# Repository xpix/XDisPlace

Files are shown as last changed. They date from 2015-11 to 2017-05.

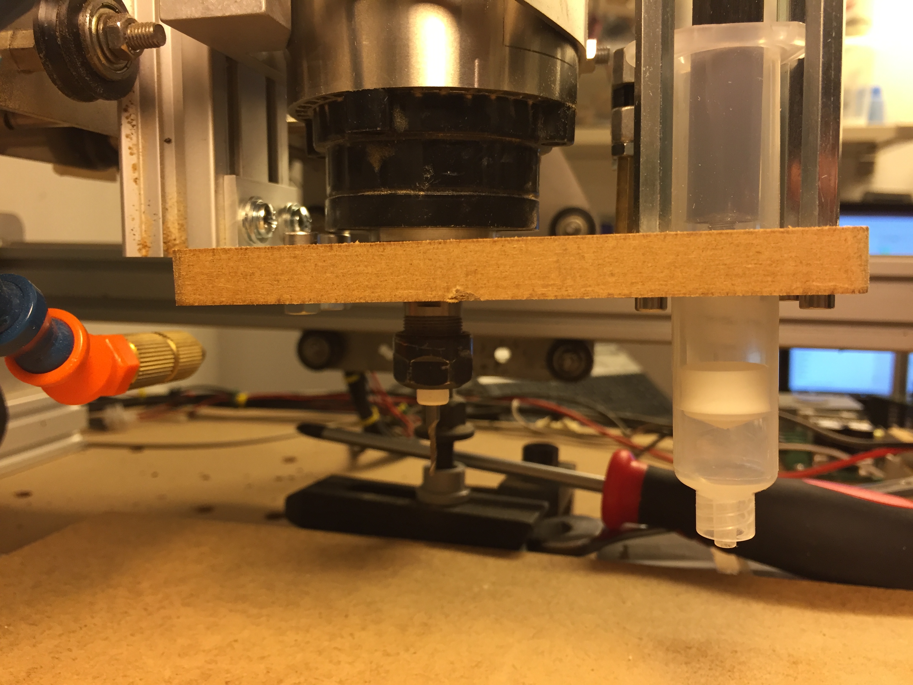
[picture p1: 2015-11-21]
Images/IMG_0289.JPG

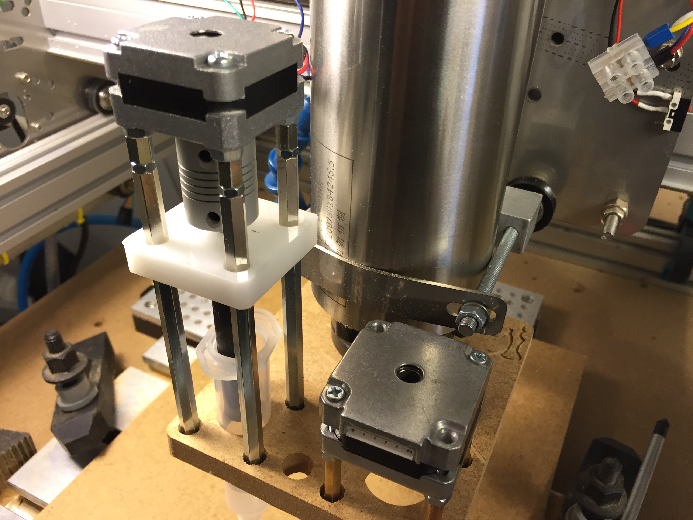
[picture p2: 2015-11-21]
Images/IMG_0288.JPG

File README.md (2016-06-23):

# XDisPlace
XDisplace are a complete solution to mill, dispense solder paste and pixk and place components to a pcb in one process!

I made a long video playlist to explain all my steps to develop this Feature. Please watch it:

Solder Dispense Feature Playlist (https://www.youtube.com/playlist?list=PLYPTUTcLMTK74VLPE4gAp8Kz8d09ipsBq)

A nice explain why XDisPlace exists from this website: http://nerdclub-uk.blogspot.de/2016/06/sacrificing-pins-to-make-pcb-layout.html

Wherever possible, we like to try to keep to single-sided boards, even for designs going "into production". While it's easy to throw together a poorly-designed, double-sided PCB and send it off to a factory to get made up, that means delays and waiting; and quite often, a much slower development cycle - particularly if, like us, you have an iterative design process!

Keeping designs to single-sides means you can knock up some ferric chloride, try out your design and have a working board in hours, not days or even weeks.

But even if your project isn't time sensitive and you can afford to wait weeks, between ordering and receiving your boards, it often means either:

a) when the board needs redesigning (because you forgot to include the ground plane, or re-route that pin you left a "to-do" note against and then ignored - don't pretend it hasn't happened) you've got another four-to-six-week wait while the new boards arrive OR

b) tack-soldering a few wires and slicing traces with a craft knife, just to get the thing up and working.

Either way, you end up with a less-than ideal PCB or weeks and months of delays.
Homebrew etching is ugly. The results are less than perfect. It's messy and you'll stain your hands yellow for days (and possibly the sink forever if you're not careful). But it gets a result - quickly.

So if you need to redesign a board, you can simply print out a new design, slap down some toner transfer, whack it in some ferric chloride and an hour or two later, you've an amended design. And once you're absolutely sure your design works, you can send the exact same PCB layout to your favourite factory/fab-house and then wait (one time only) for the nice, shiny, silk-screened-and-solder-masked versions to arrive, for the final product.

That's why we still make our own PCBs.
It might not be fashionable (in fact there are plenty people who ask why, when having PCBs manufactured is so cheap, would you want to still etch your own boards) but it is quick and allows the iterative design process to complete fully - no boards with bits of wires tacked on because we've committed to a single design now (even with faults/errors) and can't wait any longer to get the thing soldered up and tested! That's why we favour single-sided designs.

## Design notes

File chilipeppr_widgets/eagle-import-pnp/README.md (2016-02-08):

Presentation:
-------------

Philosophy:
* "simple as possible"
* no camera needed cuz accurate position of PNP Holder
* automaticly sortet components to Trays and pockets
* position on CNC in every case the same
* after homing you can use it

Platform: (Photo)
* milled in MDF, future Delron(POM) or Aluminium
* Holes for accurate position on whaste board
* Trays or Feeder numbered from 1 ... 8
* Pockets lettered from A-L
* Screw's to hold PCB in 1mm deep Pocket
* Tunnels for Probe wire's
* Calibrate block to find zero point

Strategy for Trays:
* Nozzle move the smd tape to next position
   https://youtu.be/CVlad7l9HvI?t=463
* Structure of a tray: 
   http://www.token.com.tw/chip-resistor/smd-resistor1.htm
* 1. move nozzle to zero line (cambam) of Tray
* 2. move 1.75mm in X Direction
* 3. deep nozzle in a hole 
* 4. move tape 4mm in Y direction 
* 5. go back to smd position and get it

Strategy for Pockets:
* Nozzle move the smd pocket to pocket and get smd component
   https://youtu.be/CVlad7l9HvI?t=463
* 1. move nozzle to zero line (cambam) of Tray
* 2. move 1.75mm in X Direction
* 3. deep nozzle in a hole 
* 4. move tape 4mm in Y direction 
* 5. go back to smd position and get it

PNP Plugin: 
==========
* Parameters 
   * only PNP gcode
      * send only this pnp gcode to machine
      * can use for pcb's made in china or osh park with stencil
   * packagesTrays, packagesPockets:
      * decide of this input which smd component are sorted to tray or pockets
      * user can input regular expressions (DIL\d+-SMD)
   * safetyHeight:
      * heighest point for nozzle to move without problems
      * Screw's height are ~10mm
   * RotationAxis:
      * axis on the second grbl controller to rotate the nozzle stepper for right direction
      * resistor in example
      * all roation values can see in trays/pockets table
   * Nozzle Outsidediameter
      * image: noki_nozzle.jpg 
      * diameter on the smallest side of noozle
      * use for calculate the way to next cmp in tape
   * PNP Holder
      * load pnp holder data from json file
      * designs for more holder 
      * horicontal, vertical Design

* Configure trays
   * Display table (eagle with mosfet)
   * automatic sort function to make the process very simple
   * explain Row's 
   * The components were sorted according to their value
   * same value, then same tape or pocket
   * rotation are very important for bigger components in pockets, to know for right position in pocket (check eagle package)
   * Ignored data are components they are ignored becouse thay are not exists in packagesPockets or packagesTrays

* 3D Platform model
   * Text describe the name of pocket/trays or the smd component sorted to this tray
   * the color and text let us know if the tray busy or free
   * now you can sort all components to trays/pockets

Function (physics)
* plugin load 

https://youtu.be/CVlad7l9HvI?t=297

PNP-Flow for user
------------
- calibrate
- set trays
- run PNP

A. Widget:
=========
JS
---------
* stepsCalculate() : Calculate calibrated Step settings and ask for automatic set
* calibrate() : action and run all calibration steps and save the data to localspace
* displayPlatform(model, pos) : get via JSON model and display this on 3d workspace
* getComponent( eagle component ) : get component and his position in Tray
* StrategyForGet( tray type ) : use a process in gcode to get the component from a i.e. tape
* StrategyForPut( component ) : use a process in gcode to put the component to pcb (rotate and move to correct position)
* setChannel(GPIO, on|off) : to switch GPIO on or of, check the SPJS with GPIO support
* setVacuum(on|off) : Open or close the magnetic air ventil
* onAddGcode(gcode) : add the segments to main gcode (get publish from egale-import widget)

Calculate move
--------------

- Hole in tape: 1.5mm / radius = 0.75mm
- Outsidediameter Nozzle: 1.0mm = 0.5mm
- move to corner: 0.75mm - 0.5mm = 0.25mm Y-direction
- move to next cmp: 4mm + 0.25mm = 4.25mm

HTML
---------
Checkbox to use PNP
(Calibrate Section)
* calibrateMillDiameter : calibrate mill inside diameter
* sizeCalibrateBlock : Size of calibrate Block 15.02x15.01
* Button "Calibrate"

(PNP Section)
* displayPNP : display model in 3d or not
* Button "Sort" : open a new message box with table (component / Tray)

here a try to make a flow:

1. Topic Calibrate
==================

* first be sure your Machine are calibrated. We mill a quadrat and inner circle, please measure the result with a caliper width from Box and Diameter from circle have to between 19.90 mm and 20.10 mm. (Example gcode file cambam/CalibrateExample.CalibrateBox.nc) For Z-Axis, measure the height between circle and Box, Calues between 4.95 and 5.05 are ok. 

If not between this values, then you can adjust the steps/mm for every axis. 

   I.e. You measure 19.5mm in X and Y, and your settings are 40 steps/mm. 

Formula for a probe with 
(real) 20mm diameter and 
40 steps/mm:

We need 800 steps for 20mm:
      40 steps * 20mm = 800; 

The machine measure 19.5mm:
      19,5mm / 800 = 0,024375; 

in mircon:
      20mm / 0,024375 = 820,5128205128205; 

Result are 41,026
      820,5128205128205 / 20 = 41,02564102564103; 

   Then calculate: 
      40 steps * 20mm = 800; 
      19,5mm / 800 = 0,024375; 
      20mm / 0,024375 = 820,5128205128205; 
      820,5128205128205 / 20 = 41,02564102564103;
      ==============
      use 41,025 for steps/mm

   javascript calculate:
      var orignalSteps = 40;
      var orignalDistance = 20;
      var measuredDistance = 19.5;
      var micron = (measuredDistance / (orignalSteps * orignalDistance));
      var realSteps = (orignalDistance / micron) / orignalDistance;
      
* use a used endmill with a shaft of 3.0 mm to 4mm (input box) and put this --verkehrt herum-- in collar of spindle.
* move spindle in the middle of calibrate block (camera?)
* Push Button "Calibrate" with calibrate Block in the middle of PNP Platform.
* Call Touch Plate with height 2.0mm
* Push the Button "Calibrate" and enjoy it :)

   * move to Saveheight
   * move to X-10 Y0
   * move to Z-1
   * calibrate X-Axis to touch on right side

   * move to Saveheight
   * move to X0 Y-10
   * move to Z-1
   * calibrate Y-Axis to touch on top side

   * move to Saveheight
   * move to X10 Y0
   * move to Z-1
   * calibrate X-Axis to touch on left side

   * move to Saveheight
   * move to X0 Y10
   * move to Z-1
   * calibrate Y-Axis to touch on bottom side

* calculate (X/Y)Pos -/+ (inoutdiamter/2), care over sizeCalibrateBlock
* We know the position of the calibrate block. With this information we know everything about position of trays and PCB etc.pp.
* IMPORTANT: Save the Machineposition on a localspace to help user. If you lose this position, than you can home your machine and go back to this position to find you center/zero point of PNP Platform!
* Drive the calibrate crosshairs on left/right/top with camera and check if cross in middle

Done as Calibrate Widget: 
http://chilipeppr-calibrate-xpix.c9users.io/

Topic PickAndPlace
==================

* Display PNP Platform as 3d Object in 3d world (table with data load as ajax) use threejs/editor to build a model
* load JSON Table with positions of all trays and PCB Holder
* Display a Table with all Trays and a list of components
   * getComponent( eagle component );
      - get and move to tray position
      - get strategy to get a component
      - write gcode
   * setComponent( eagle component );
      - get and move to pcb position
      - get put strategy to put a component to pcb
      - write gcode

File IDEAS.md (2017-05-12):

Here some intresting links for SolderDispenser:

## use soldermask widget from j.lauer

to generate the gcode we have to use a formula, i found this in slicr:
  https://github.com/alexrj/Slic3r/blob/master/lib/Slic3r/GCode/PressureRegulator.pm#L39-L63
````
# First calculate relative flow rate (mm of filament over mm of travel)
my $rel_flow_rate = $info->{dist_E} / $info->{dist_XY};

# Then calculate absolute flow rate (mm/sec of feedstock)
my $flow_rate = $rel_flow_rate * $F / 60;

# And finally calculate advance by using the user-configured K factor.
my $new_advance = $self->config->pressure_advance * ($flow_rate**2);
````

Think about the simplest workflow for dispenser:
*   use the flow of 3d print
*   means first make a line with calculatet 0.2mm on the side off pcb (length & witdth configurable)
*   build a webservice dispense, this will translate coordinates to dispenser gcode

````
start 10,10;end 20,10;fill:rectangle
json='"start":[10,10], 
     "end":[20,20],
     "fill":"rectangle"     '
````
Will translate to fill, use modified slicr modul for this on server.
It's able to use the Fill Modules from Slicr:
````
# honeycomp example:
    my $pattern = 'honeycomb';
    my $config = Slic3r::Config->new_from_defaults;
    $config->set('fill_pattern', $pattern);
    $config->set('external_fill_pattern', $pattern);
    $config->set('perimeters', 1);
    $config->set('skirts', 0);
    $config->set('fill_density', 20);
    $config->set('layer_height', 0.05);
    $config->set('perimeter_extruder', 1);
    $config->set('infill_extruder', 2);
    my $print = Slic3r::Test::init_print('20mm_cube', config => $config, scale => 2);
    my $gcode = Slic3r::Test::gcode($print);
````

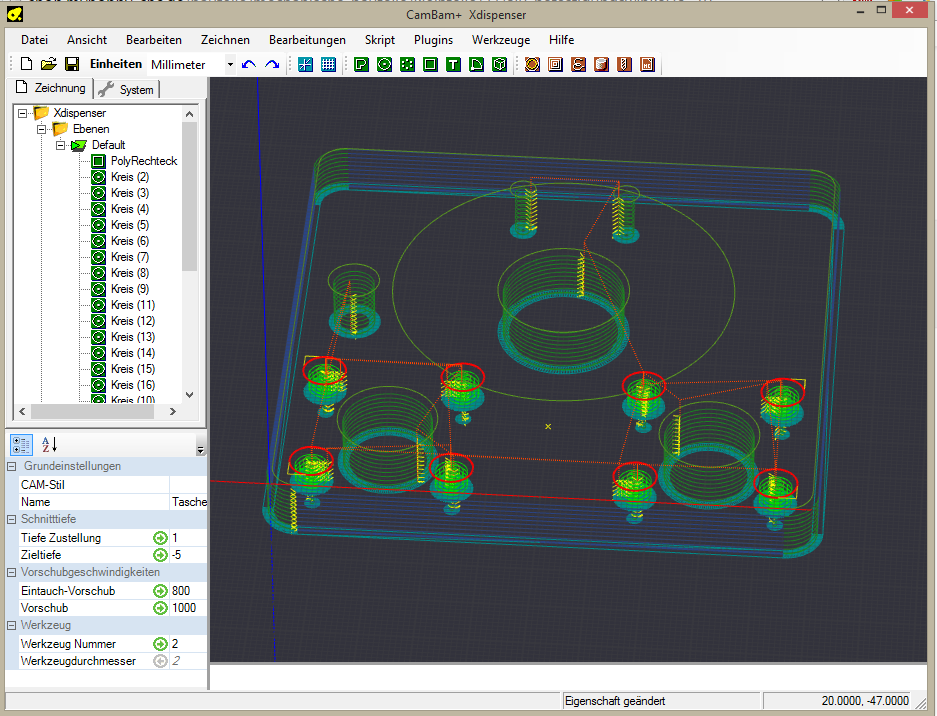
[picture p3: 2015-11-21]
Images/cambam-plus-0.9.1_s.png

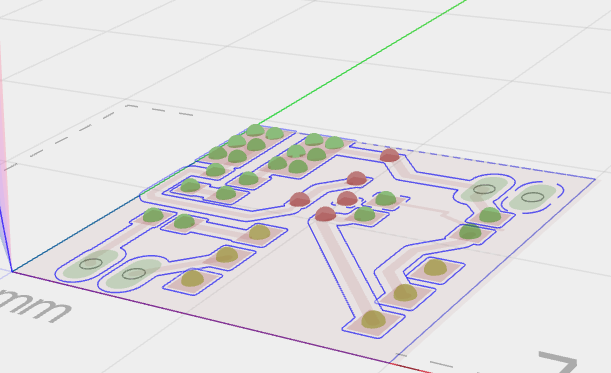
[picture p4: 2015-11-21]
Images/Drops.PNG

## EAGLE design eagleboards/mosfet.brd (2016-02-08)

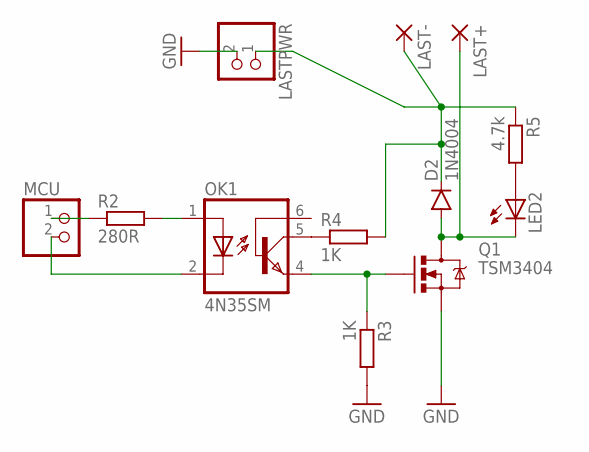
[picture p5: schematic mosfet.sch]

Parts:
D2: 1N4004; SOD-123
LAST+: WIREPADSMD2,54-5,08; SMD2,54-5,08
LAST-: WIREPADSMD2,54-5,08; SMD2,54-5,08
LASTPWR: PINHD-1X2; 1X02
LED2: LEDCHIP-LED0805; CHIP-LED0805
MCU: PINHD-1X2; 1X02
OK1: 4N35SM; DIL6-SMD
Q1: TSM3404; SOT23-3
R2: 280R; R0805
R3, R4: 1K; R0805
R5: 4.7k; R0805

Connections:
GND: LASTPWR.2, Q1.2 (S), R3.2
LAST+: D2.C, LAST-.1, LASTPWR.1, R4.2, R5.1
LAST-: D2.A, LAST+.1, LED2.C, Q1.3 (D)
unnamed: OK1.1 (A), R2.2
unnamed: MCU.1, R2.1
unnamed: MCU.2, OK1.2 (C)
unnamed: OK1.4 (EMI), Q1.1 (G), R3.1
unnamed: OK1.5 (COL), R4.1
unnamed: LED2.A, R5.2

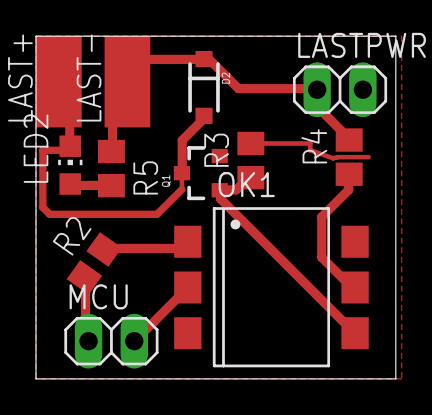
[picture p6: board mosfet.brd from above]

Board: 2 copper layers, 20.0 x 19.0 mm, 12 parts (0 on the bottom side), 9 nets.

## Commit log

2015-11-21 Initialize Project
    [mosfet.brd, mosfet.sch]
2015-12-01 - add calibrate gcode
2015-12-01 imporove calibrate code for dispenser
2015-12-14 - add dispenser widget - add onoholder cambam project - add camera widget
    [PnPHolder.dxf, pnp-test.brd, pnp-test.sch]
2015-12-15 - add initial flow informations
2016-02-08 - new files - some changes
    [PnPHolder.dxf, mosfet.brd, mosfet.sch]
2016-02-10 - remove obsolete files
    [PnPHolder.dxf]

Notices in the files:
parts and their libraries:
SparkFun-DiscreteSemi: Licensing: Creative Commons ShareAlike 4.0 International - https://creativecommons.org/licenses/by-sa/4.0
